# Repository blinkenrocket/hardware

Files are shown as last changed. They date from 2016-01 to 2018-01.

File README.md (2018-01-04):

# Hardware
This repository contains schematics, board layout and the BOM
## Expansion Headers
Blinkenrocket features expansion headers which makes un-used pins available for use. Pins are broken out on standard 2.54mm pin headers (need to be soldered on separately). VCC and GND are added for convenience. If you look at the CPU on the back the layout is as follows:

```
VCC                     VCC
E1         [CPU]         E3
E2         [CPU]         E4
GND                     GND
```

The pins map to the following pins on the microcontroller:

E1: PC0 (ADC0/PCINT8)

E2: PC1 (ADC1/PCINT9)

E3: PC2 (ADC2/PCINT10)

E4: PA1 (ADC7/PCINT25)

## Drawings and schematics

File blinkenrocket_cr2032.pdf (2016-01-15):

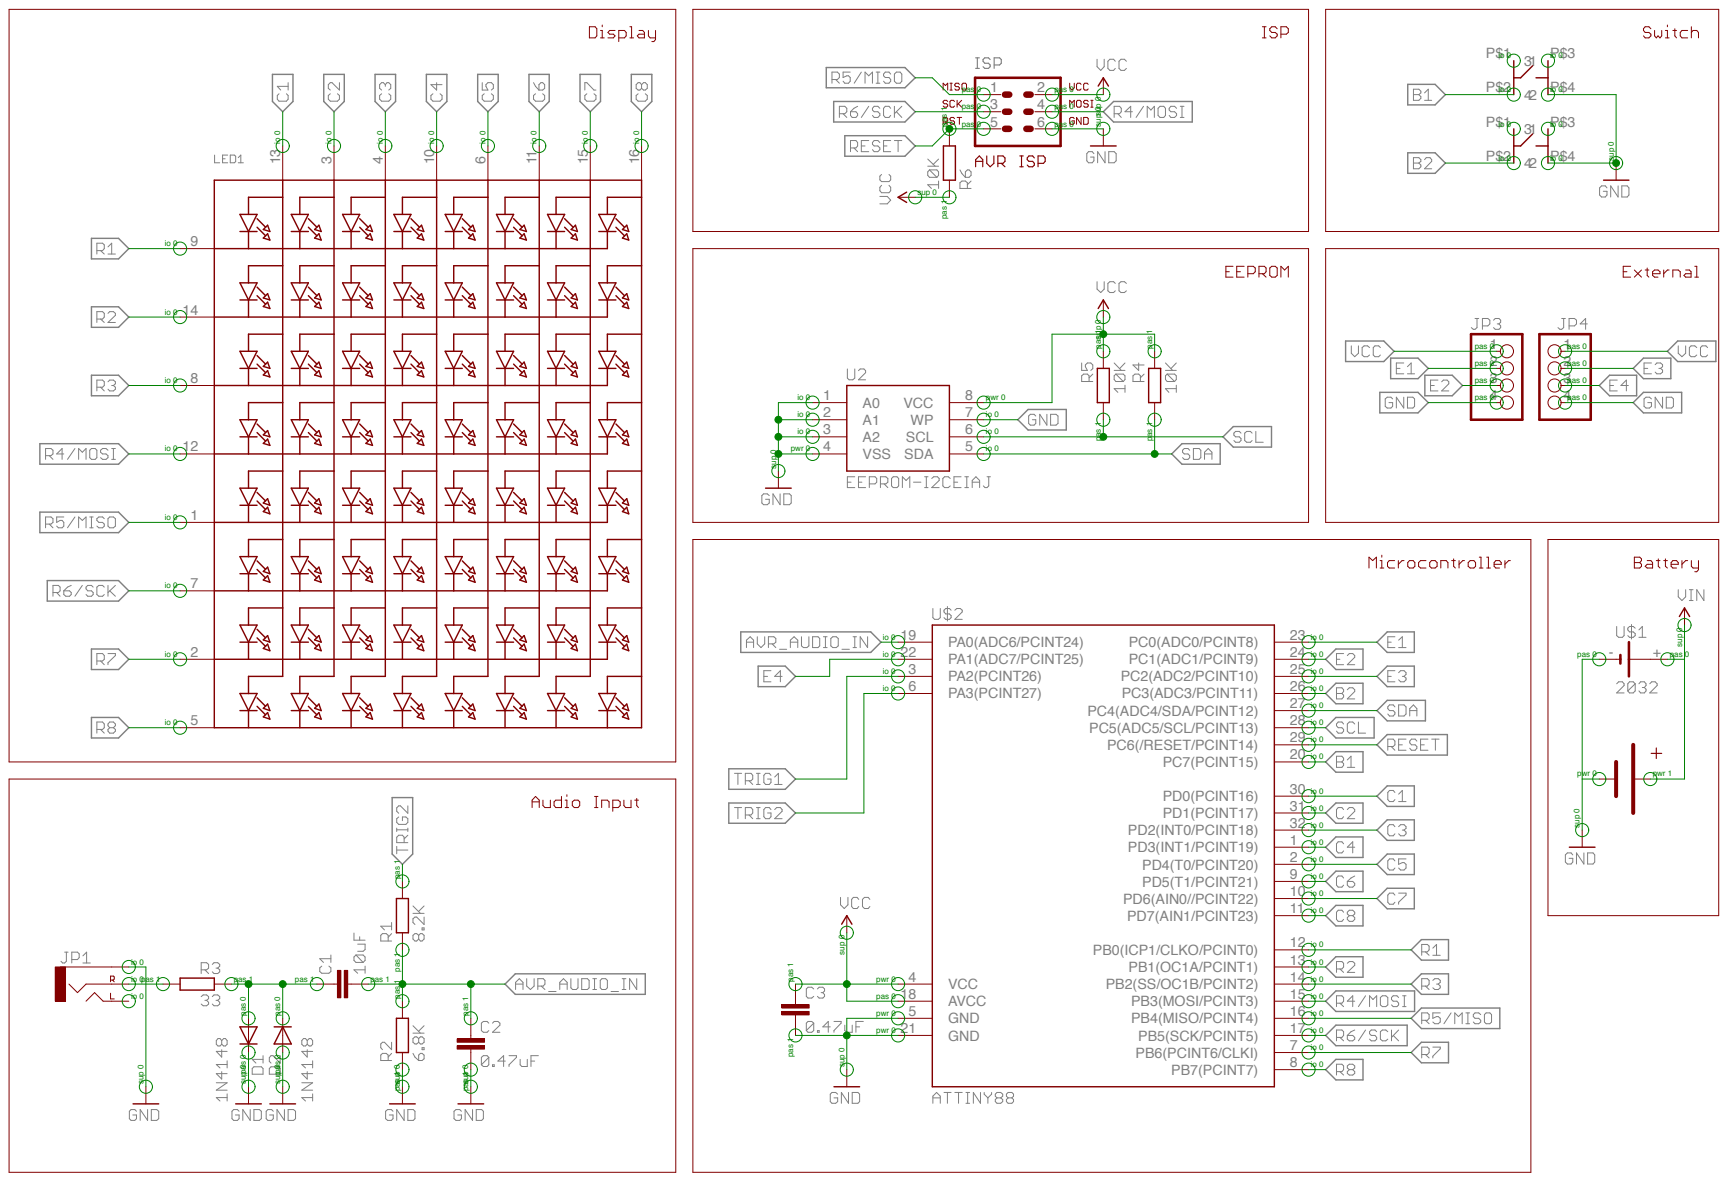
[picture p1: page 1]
PB5(SCK/PCINT5); PB7(PCINT7); 8 PB6(PCINT6/CLKI); PA2(PCINT26); VCC; GND; PC7(PCINT15); AVCC 18; PB4(MISO/PCINT4); 16 PB3(MOSI/PCINT3); 15 PB2(SS/OC1B/PCINT2); 14 PB1(OC1A/PCINT1); 13 PB0(ICP1/CLKO/PCINT0); PD7(AIN1/PCINT23); 11 PD6(AIN0//PCINT22); 10 PD5(T1/PCINT21); 9 PD4(T0/PCINT20); 2 PD3(INT1/PCINT19); 1 PD2(INT0/PCINT18); 32 PD1(PCINT17); 31 PD0(PCINT16); PC5(ADC5/SCL/PCINT13); 28 PC4(ADC4/SDA/PCINT12); 27 PC3(ADC3/PCINT11); 26 PC2(ADC2/PCINT10); 25 PC1(ADC1/PCINT9); 24 PC0(ADC0/PCINT8)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

pas 1 pas 1

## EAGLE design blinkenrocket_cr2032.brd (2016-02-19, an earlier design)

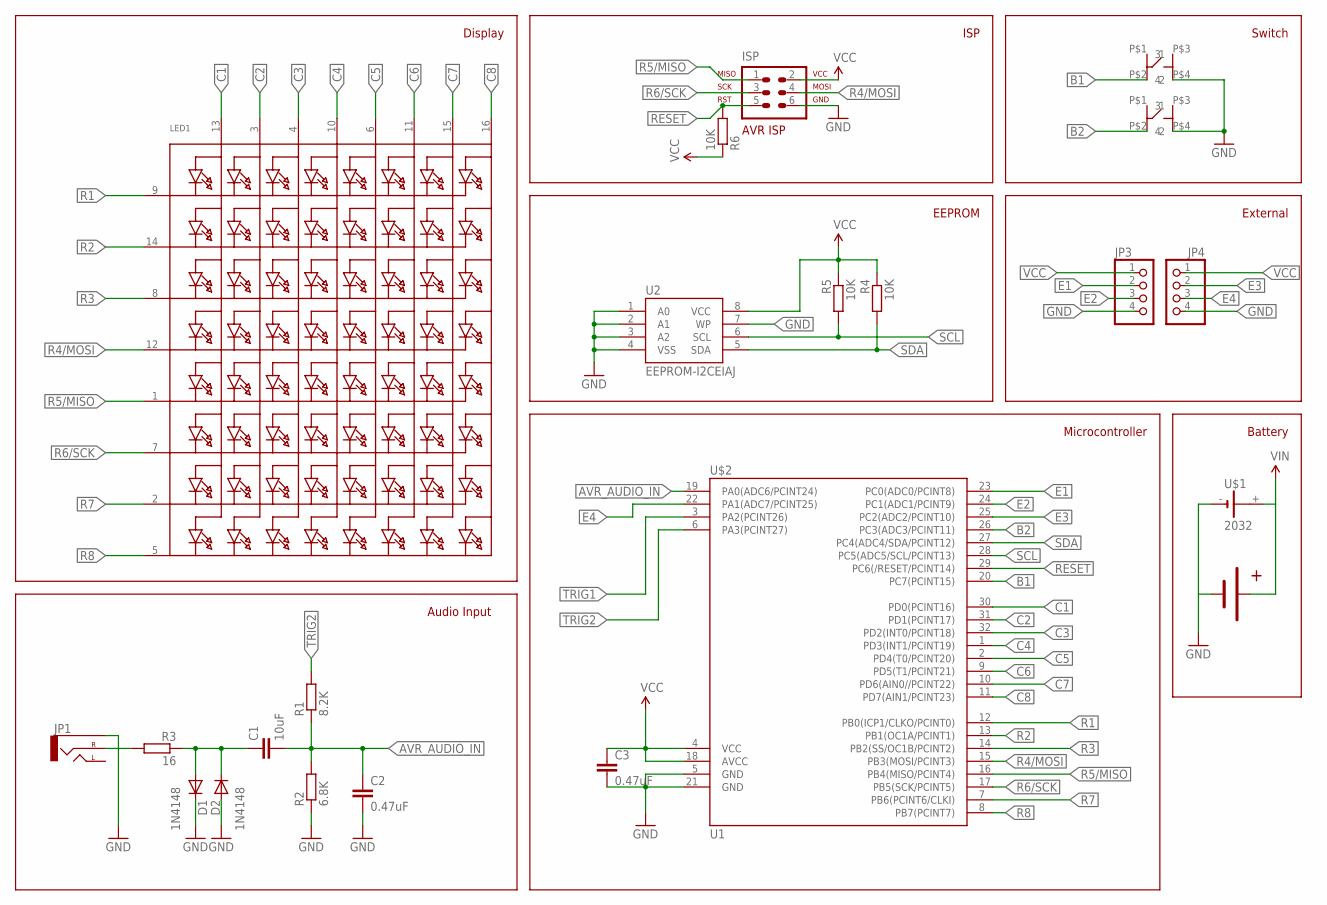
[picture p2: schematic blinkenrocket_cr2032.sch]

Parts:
C1: 10uF; C1206
C2, C3: 0.47uF; C1206
D1, D2: 1N4148; SOD3718X135N
ISP: AVR-ISP-6VERT; AVR-ISP-6
JP1: AUDIO-JACKPTH; AUDIO-JACK
JP3, JP4: PINHD-1X04_2.54-S; 1X04-S
LED1: SEGMENT_8X8_ROWCATHODEM12A881UR; SEGMENT_BL-M12A881UR
R1: 8.2K; R1206
R2: 6.8K; R1206
R3: 16; R1206
R4, R5, R6: 10K; R1206
SW1, SW2: SWITCH-4POMRON-6-6-SWITCH; 4P-OMRON-6-6-SWITCH
U2: EEPROM-I2CEIAJ; SO08-EIAJ
U$1: 2032; KZH20SMD
U$2: U1; TQFP32-08
U$3: BATTERYPAD

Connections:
AVR_AUDIO_IN: C1.2, C2.1, R1.1, R2.2, U$2.19 (PA0(ADC6/PCINT24))
B1: SW2.P$2 (2), U$2.20 (PC7(PCINT15))
B2: SW1.P$2 (2), U$2.26 (PC3(ADC3/PCINT11))
C1: LED1.13 (A1), U$2.30 (PD0(PCINT16))
C2: LED1.3 (A2), U$2.31 (PD1(PCINT17))
C3: LED1.4 (A3), U$2.32 (PD2(INT0/PCINT18))
C4: LED1.10 (A4), U$2.1 (PD3(INT1/PCINT19))
C5: LED1.6 (A5), U$2.2 (PD4(T0/PCINT20))
C6: LED1.11 (A6), U$2.9 (PD5(T1/PCINT21))
C7: LED1.15 (A7), U$2.10 (PD6(AIN0//PCINT22))
C8: LED1.16 (A8), U$2.11 (PD7(AIN1/PCINT23))
E1: JP3.2, U$2.23 (PC0(ADC0/PCINT8))
E2: JP3.3, U$2.24 (PC1(ADC1/PCINT9))
E3: JP4.2, U$2.25 (PC2(ADC2/PCINT10))
E4: JP4.3, U$2.22 (PA1(ADC7/PCINT25))
GND: C2.2, C3.2, D1.K, D2.A, ISP.6, JP1.SLEEVE, JP3.4, JP4.4, R2.1, SW1.P$4 (4), SW2.P$4 (4), U2.1 (A0), U2.2 (A1), U2.3 (A2), U2.4 (VSS), U2.7 (WP), U$1.-, U$2.5 (GND), U$2.21 (GND), U$3.-VE
unnamed: JP1.RING (RIGHT), R3.2
unnamed: C1.1, D1.A, D2.K, R3.1
R1: LED1.9 (K1), U$2.12 (PB0(ICP1/CLKO/PCINT0))
R2: LED1.14 (K2), U$2.13 (PB1(OC1A/PCINT1))
R3: LED1.8 (K3), U$2.14 (PB2(SS/OC1B/PCINT2))
R4/MOSI: ISP.4, LED1.12 (K4), U$2.15 (PB3(MOSI/PCINT3))
R5/MISO: ISP.1, LED1.1 (K5), U$2.16 (PB4(MISO/PCINT4))
R6/SCK: ISP.3, LED1.7 (K6), U$2.17 (PB5(SCK/PCINT5))
R7: LED1.2 (K7), U$2.7 (PB6(PCINT6/CLKI))
R8: LED1.5 (K8), U$2.8 (PB7(PCINT7))
RESET: ISP.5, R6.2, U$2.29 (PC6(/RESET/PCINT14))
SCL: R5.2, U2.6 (SCL), U$2.28 (PC5(ADC5/SCL/PCINT13))
SDA: R4.2, U2.5 (SDA), U$2.27 (PC4(ADC4/SDA/PCINT12))
TRIG1: U$2.3 (PA2(PCINT26))
TRIG2: R1.2, U$2.6 (PA3(PCINT27))
VCC: C3.1, ISP.2, JP3.1, JP4.1, R4.1, R5.1, R6.1, U2.8 (VCC), U$1.+, U$2.4 (VCC), U$2.18 (AVCC), U$3.+VE

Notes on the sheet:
Audio Input
Display
ISP
Switch
Battery
EEPROM
Microcontroller
External

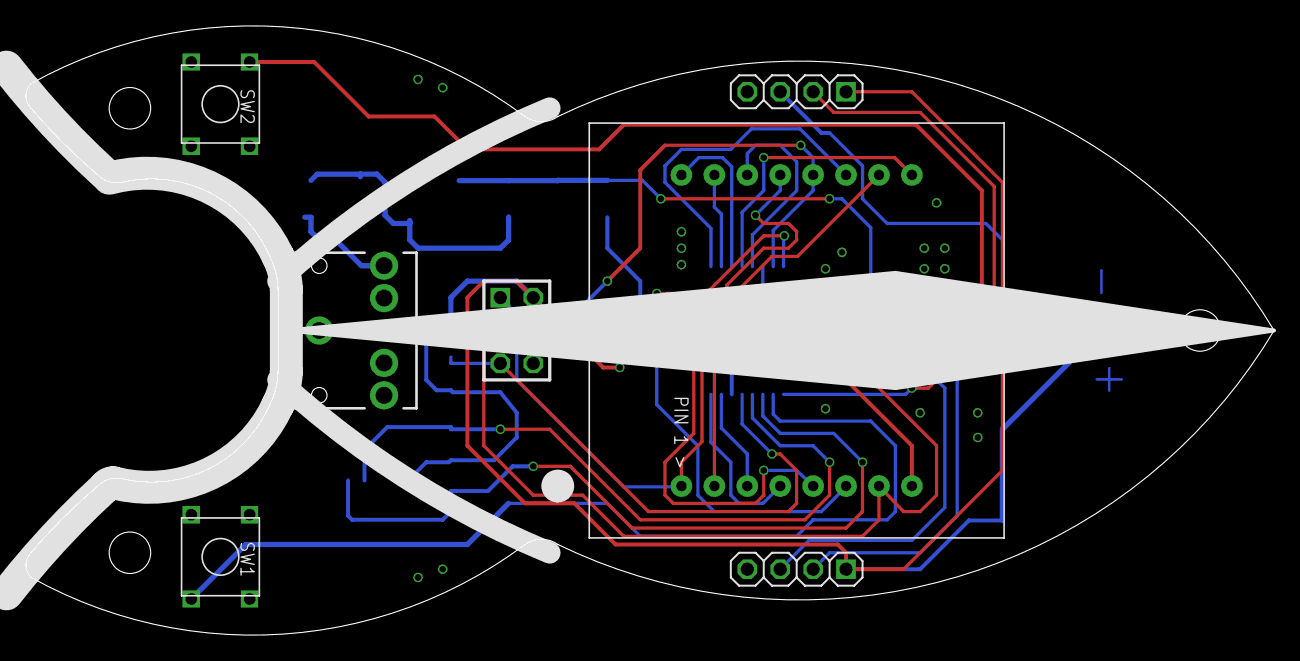
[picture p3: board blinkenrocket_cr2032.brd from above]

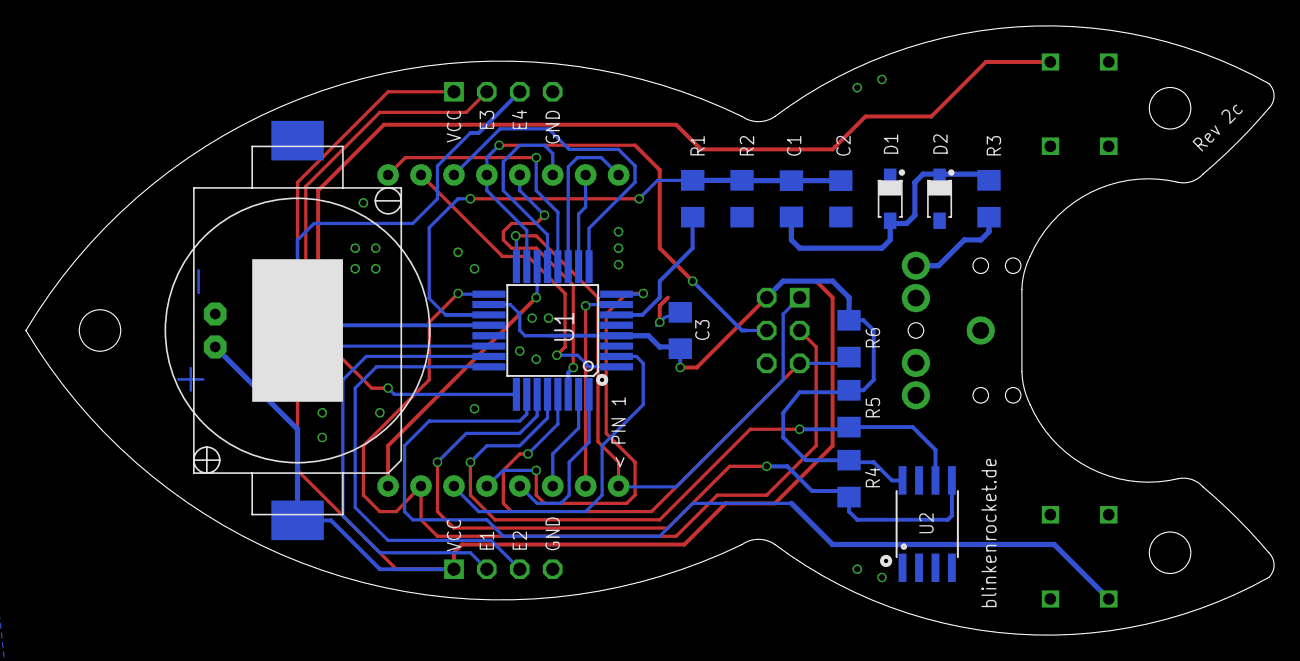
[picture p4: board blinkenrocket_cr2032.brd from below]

Board: 2 copper layers, 96.3 x 47.0 mm, 22 parts (15 on the bottom side), 31 nets.

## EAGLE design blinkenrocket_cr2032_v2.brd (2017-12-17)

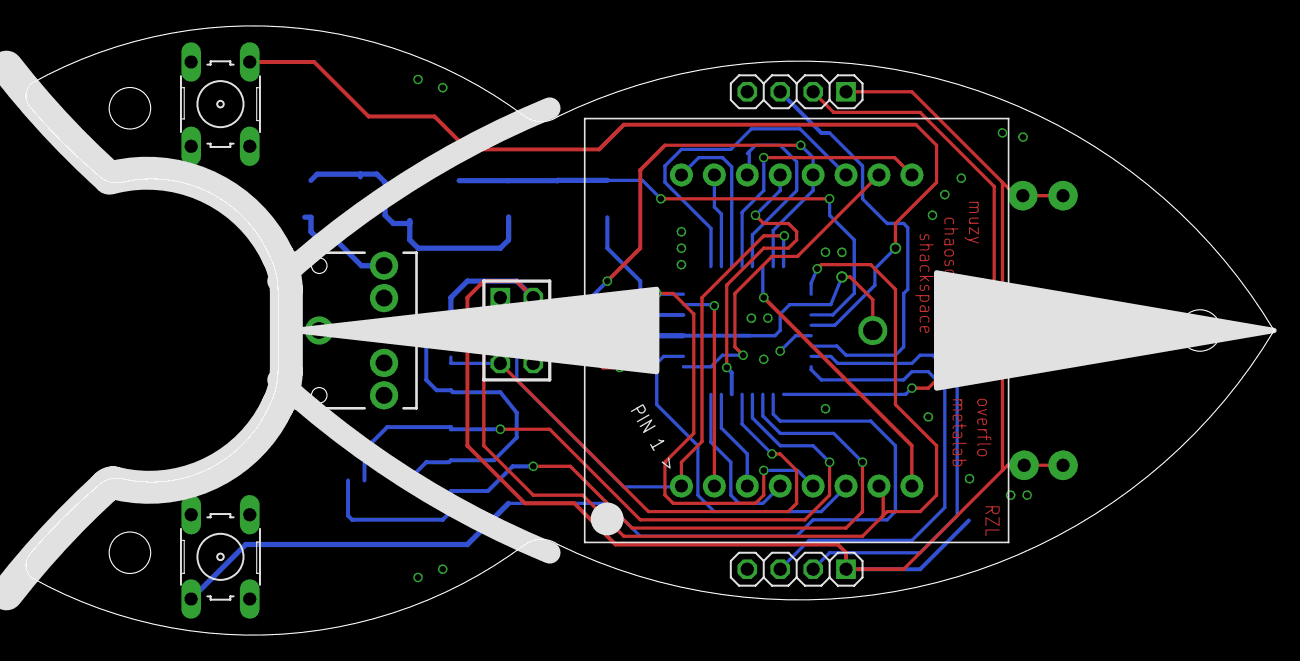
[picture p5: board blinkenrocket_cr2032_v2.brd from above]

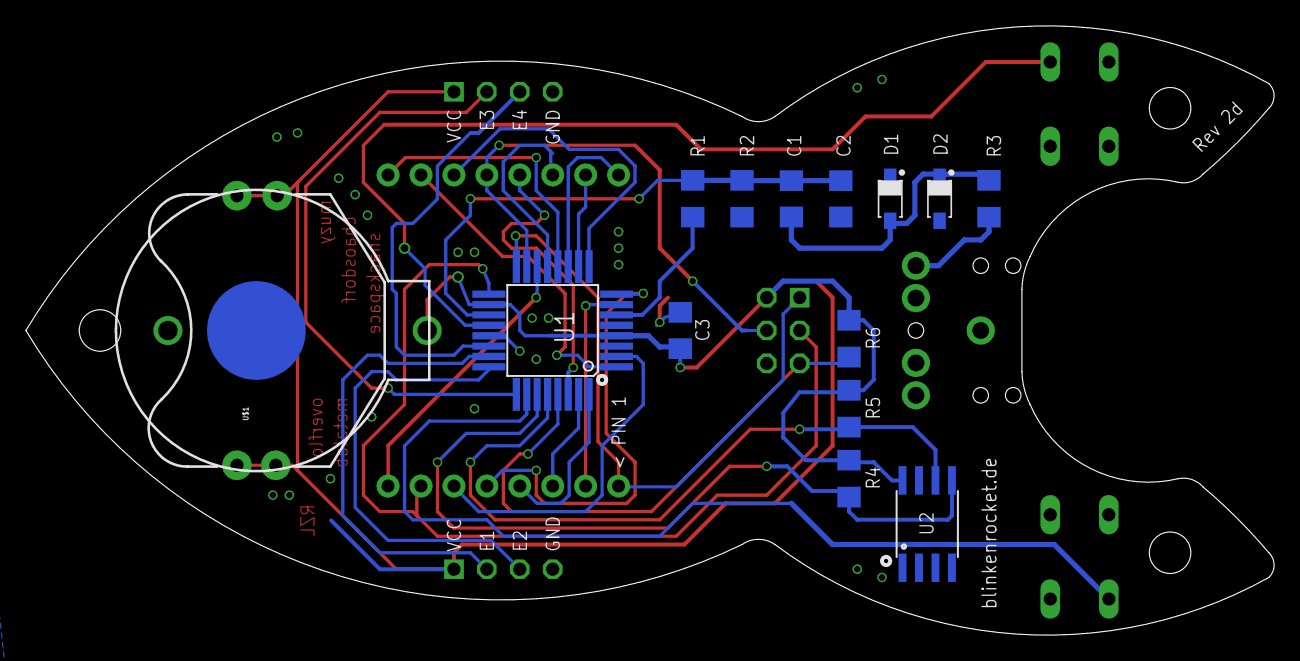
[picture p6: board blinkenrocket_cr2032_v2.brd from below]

Board: 2 copper layers, 96.3 x 47.0 mm, 22 parts (15 on the bottom side), 31 nets.

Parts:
C1: 10uF; C1206
C2, C3: 0.47uF; C1206
D1, D2: 1N4148; SOD3718X135N
ISP: AVR-ISP-6VERT; AVR-ISP-6
JP1: AUDIO-JACK
JP3, JP4: 1X04-S
LED2: SEGMENT_BL-M12A883
R1: 8.2K; R1206
R2: 6.8K; R1206
R3: 16; R1206
R4, R5, R6: 10K; R1206
S1, S2: B3F-10XX
U2: EEPROM-I2CEIAJ; SO08-EIAJ
U$1: LINX-BAT-HLD-001-TH; BAT_20MM_TH
U$2: U1; TQFP32-08
U$5: CR2032_ELECTRODRAGON; CR2032PAC_ELECTRODRAGON

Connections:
AVR_AUDIO_IN: C1.2, C2.1, R1.1, R2.2, U$2.19
B1: S2.1, U$2.20
B2: S1.1, U$2.26
C1: LED2.13, U$2.30
C2: LED2.3, U$2.31
C3: LED2.4, U$2.32
C4: LED2.10, U$2.1
C5: LED2.6, U$2.2
C6: LED2.11, U$2.9
C7: LED2.15, U$2.10
C8: LED2.16, U$2.11
E1: JP3.2, U$2.23
E2: JP3.3, U$2.24
E3: JP4.2, U$2.25
E4: JP4.3, U$2.22
GND: C2.2, C3.2, D1.K, D2.A, ISP.6, JP1.SLEEVE, JP3.4, JP4.4, R2.1, S1.3, S2.3, U2.1, U2.2, U2.3, U2.4, U2.7, U$1.GND, U$2.5, U$2.21, U$5.-
unnamed: JP1.RING, R3.2
unnamed: C1.1, D1.A, D2.K, R3.1
R1: LED2.9, U$2.12
R2: LED2.14, U$2.13
R3: LED2.8, U$2.14
R4/MOSI: ISP.4, LED2.12, U$2.15
R5/MISO: ISP.1, LED2.1, U$2.16
R6/SCK: ISP.3, LED2.7, U$2.17
R7: LED2.2, U$2.7
R8: LED2.5, U$2.8
RESET: ISP.5, R6.2, U$2.29
SCL: R5.2, U2.6, U$2.28
SDA: R4.2, U2.5, U$2.27
TRIG2: R1.2, U$2.6
VCC: C3.1, ISP.2, JP3.1, JP4.1, R4.1, R5.1, R6.1, U2.8, U$1.VCC1, U$1.VCC2, U$1.VCC3, U$1.VCC4, U$2.4, U$2.18, U$5.+

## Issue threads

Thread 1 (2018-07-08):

Only .brd included for v2, there is no .sch file

claudiucherciu, 2018-07-08:
blinkenrocket_cr2032_v2.brd has no corresponding .sch file, making it difficult to work in Eagle for small adjustments.

muzy, 2018-07-08:
Actually the .sch is the same, as only the .brd layout was changed. You may copy the file/rename it to make it easier to work with.

By the way: if you change something feel free to create a pull request.

claudiucherciu, 2018-07-08:
Thanks for replying. Here is my sch, copied and adjusted whatever I could (SW1->S1, SW2 -> S2, LED2 -> LED1), but some packages are also changed, that's why I asked.

Attached is the sch _v2 I managed to get to, up to now..

[blinkenrocket_cr2032_v2.zip](https://github.com/blinkenrocket/hardware/files/2173687/blinkenrocket_cr2032_v2.zip)

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

muzy, 2018-07-08:
Thanks for the hint, I'll check that and get back to you.

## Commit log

2016-01-09 Initial transfer from old repository
    [blinkenrocket_cr2032.brd, blinkenrocket_cr2032.sch]
2016-01-15 make the powersupply of the modem part switchable by the IC for powersaving reasons
    [blinkenrocket_cr2032.brd, blinkenrocket_cr2032.sch]
2016-01-15 add new schematic with switchable button
2016-01-16 add revision information (R2a)
    [blinkenrocket_cr2032.brd]
2016-01-22 make the audio signal more straight to reduce the antenna effect
    [blinkenrocket_cr2032.brd]
2016-01-22 adjusted revision tag
    [blinkenrocket_cr2032.brd]
2016-02-12 change value of modem input resistor
    [blinkenrocket_cr2032.brd, blinkenrocket_cr2032.sch]
2016-02-19 Revision 2c - diodes do have positioning information now - added blinkenrocket.de text - add IC component name
    [blinkenrocket_cr2032.brd, blinkenrocket_cr2032.sch]
2016-02-19 straighten one trace
    [blinkenrocket_cr2032.brd]
2017-12-17 Add Version 2 with different battery holder
    [blinkenrocket_cr2032_v2.brd]

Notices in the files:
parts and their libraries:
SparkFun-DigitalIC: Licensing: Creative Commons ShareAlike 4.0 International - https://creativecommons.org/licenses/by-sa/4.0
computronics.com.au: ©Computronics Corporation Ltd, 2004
